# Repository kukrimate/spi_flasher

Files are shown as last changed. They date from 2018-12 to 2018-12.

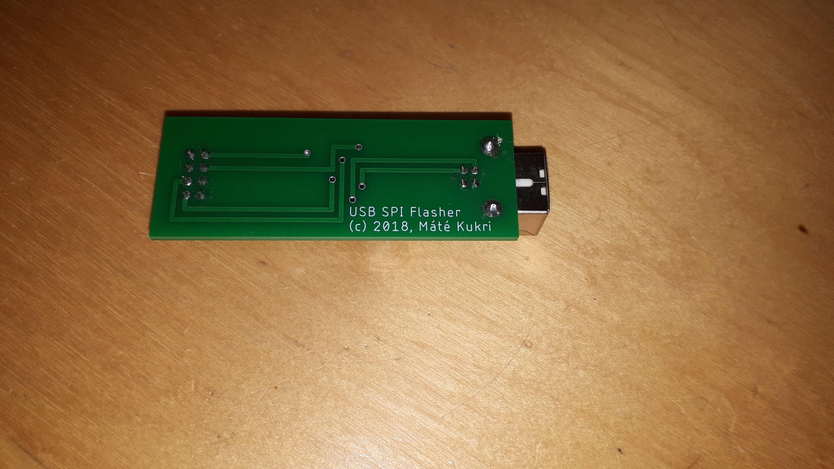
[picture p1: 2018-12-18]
pictures/board_backside.jpg

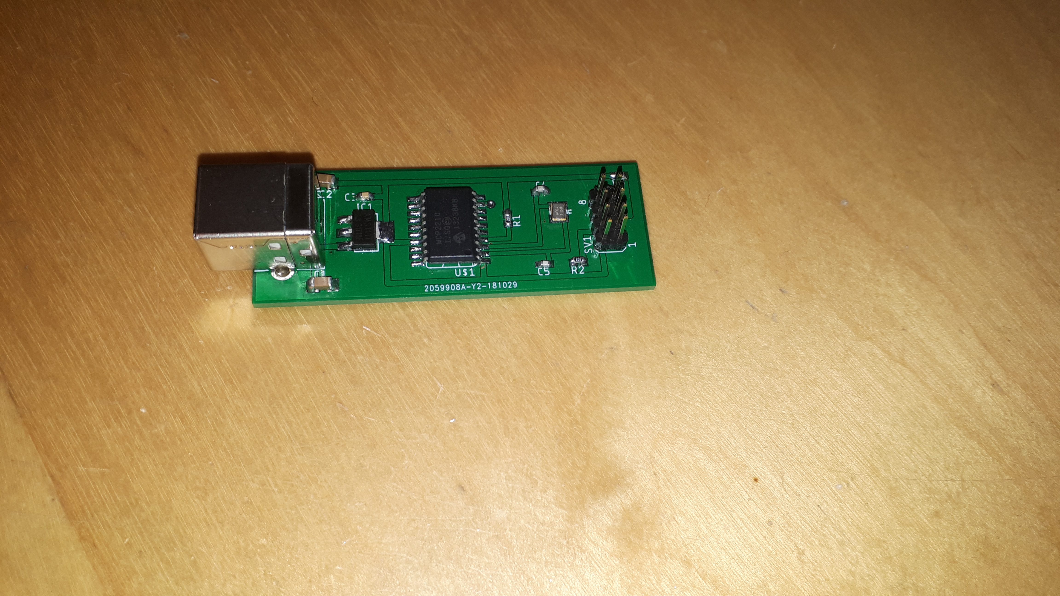
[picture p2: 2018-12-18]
pictures/board_topside.jpg

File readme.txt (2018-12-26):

This project contains a schematic and board design for a breakout board for
the Microchip MCP2210 with a pin header to connect an SPI flash device.

Both files are in the file format of EAGLE from Autodesk.

Assembly suggestions: Use a very fine tipped soldering iron set to 300-350 C,
use very small diameter rosin core solder wire and DO use extra flux.

In the `pictures` directory you can see some high resolution pictures taken
of a device built (hand-soldered) using this design.

For software, for now you can use my modified version of flashrom. Hopefully
support for this will be upstreamed soon.
It supports both libusb (mcp2210_libusb branch) and directly using the hidraw
kernel interface on Linux.
https://github.com/kukrimate/flashrom

==== COPYING ====

Any person obtaining a copy of this schematic and board design is permitted to
use, modify and/or distribute this schematic and board design for any purpose,
including, but not limited to commercial use with the only requirement
of not removing the copyright notice from the board silkscreen.

==== IMPORTANT DISCLAIMER ====

THE SCHEMATIC AND BOARD DESIGN IS PROVIDED "AS IS"
AND THE AUTHOR DISCLAIMS ALL WARRANTIES WITH REGARD TO THIS
SCHEMATIC AND BOARD DESIGN INCLUDING ALL IMPLIED WARRANTIES OF
MERCHANTABILITY AND FITNESS. IN NO EVENT SHALL THE AUTHOR BE LIABLE FOR
ANY SPECIAL, DIRECT, INDIRECT, OR CONSEQUENTIAL DAMAGES OR ANY DAMAGES
WHATSOEVER RESULTING FROM LOSS OF USE, DATA OR PROFITS, WHETHER IN AN
ACTION OF CONTRACT, NEGLIGENCE OR OTHER TORTIOUS ACTION, ARISING OUT OF
OR IN CONNECTION WITH THE USE OR PERFORMANCE OF THE SCHEMATIC AND/OR BOARD
DESIGN OR ANY DEVICE BUILT OR MANUFACTURED FROM THEM.

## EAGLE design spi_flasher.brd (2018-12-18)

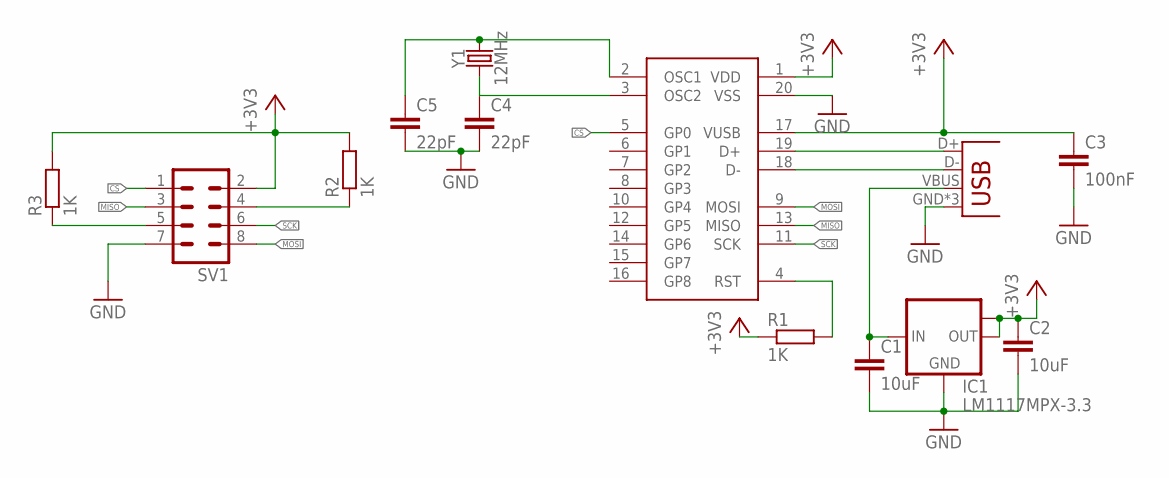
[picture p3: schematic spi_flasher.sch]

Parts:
C1, C2: 10uF; C1206
C3: 100nF; C0603
C4, C5: 22pF; C0603
IC1: LM1117MPX-3.3; SOT223
R1, R2, R3: 1K; R0603
SV1: MA04-2
U$1: MCP2210-I/SO; SO20L
X1: USBPTH; USB-B-PTH
Y1: 12MHz; CRYSTAL-SMD-3.2X2.5MM

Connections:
+3V3: C2.1, C3.1, IC1.2 (OUT), IC1.TAB (OUT1), R1.1, R2.2, R3.2, SV1.2, U$1.1 (VDD), U$1.17 (VUSB)
CS: SV1.1, U$1.5 (GP0)
GND: C1.2, C2.2, C3.2, C4.2, C5.2, IC1.1 (GND), SV1.7, U$1.20 (VSS), X1.GND, X1.P$1 (GND), X1.P$2 (GND)
MISO: SV1.3, U$1.13 (MISO)
MOSI: SV1.8, U$1.9 (MOSI)
unnamed: U$1.19 (D+), X1.D+
unnamed: U$1.18 (D-), X1.D-
unnamed: C4.1, U$1.3 (OSC2), Y1.1
unnamed: C1.1, IC1.3 (IN), X1.VBUS
unnamed: C5.1, U$1.2 (OSC1), Y1.3 (2)
unnamed: R1.2, U$1.4 (RST)
unnamed: R3.1, SV1.5
unnamed: R2.1, SV1.4
SCK: SV1.6, U$1.11 (SCK)

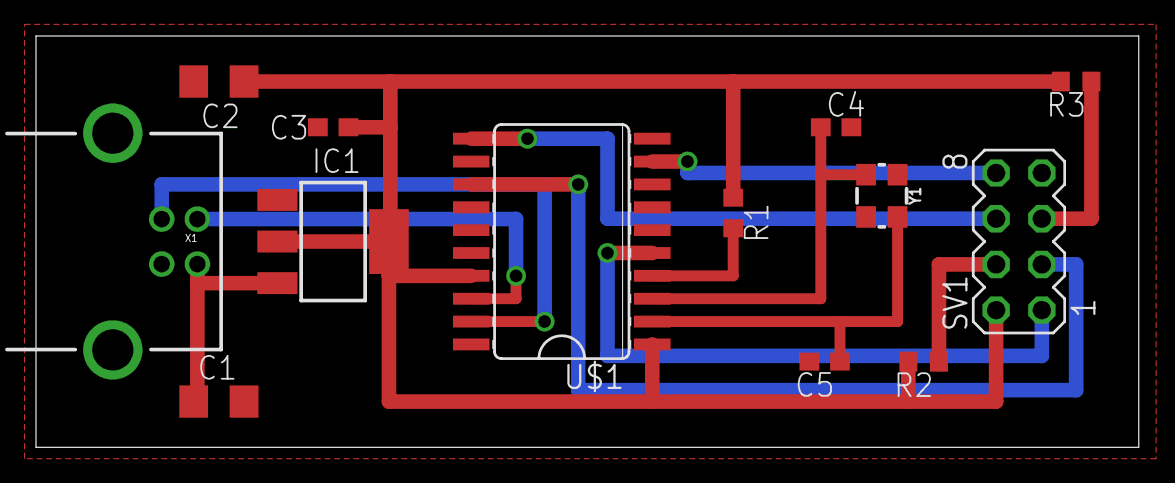
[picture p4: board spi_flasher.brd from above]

Board: 2 copper layers, 61.3 x 22.9 mm, 13 parts (0 on the bottom side), 14 nets.

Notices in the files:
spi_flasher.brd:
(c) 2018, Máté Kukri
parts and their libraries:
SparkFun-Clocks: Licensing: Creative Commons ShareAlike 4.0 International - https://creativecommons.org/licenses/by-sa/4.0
